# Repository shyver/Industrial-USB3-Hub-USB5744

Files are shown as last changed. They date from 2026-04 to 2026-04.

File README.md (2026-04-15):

# Industrial 4-Port USB 3.0 Hub (High-Speed Design)






## 📌 Project Overview
This repository contains the hardware design files for an industrial-grade, 4-port USB 3.0 (SuperSpeed 5Gbps) Hub. 

Designed around the **Microchip USB5744** hub controller, this project demonstrates advanced high-speed digital PCB design. It features a strict 4-layer stackup, precisely calculated 90Ω differential impedance routing, length-matching, robust ESD protection, and independent per-port power management. 

It is engineered to reliably convert a single USB-C upstream connection into four high-speed USB-A downstream ports in harsh or demanding environments.

*(Insert a screenshot of your routed PCB showing the differential pairs here later!)*

## ✨ Key Hardware Features
* **SuperSpeed Data (5 Gbps):** Full USB 3.1 Gen 1 compliance utilizing edge-coupled differential microstrip routing.
* **Impedance Control:** Mathematically calculated 90Ω differential impedance ($Z_{diff}$) tuned specifically for the JLC04161H-3313 manufacturing stackup.
* **Industrial Power Distribution:** Integrated power load switches providing dedicated, current-limited 5V power to each downstream port to prevent cascading short-circuit failures.
* **Heavy-Duty ESD Protection:** Ultra-low capacitance (< 0.5pF) TVS diode arrays on all SuperSpeed data lines to absorb transient voltage spikes without distorting multi-gigabit signal integrity.
* **Clean Clocking:** 25MHz external crystal oscillator with localized ground guarding to minimize EMI/Crosstalk.

## 📐 High-Speed PCB Specifications

To achieve reliable 5 Gbps data rates, standard 2-layer routing is insufficient. This board utilizes a custom 4-layer stackup to provide immediate, unbroken return paths for high-frequency signals.

* **Stackup Architecture:**
  * **Layer 1 (Top):** High-Speed Signals
  * **Layer 2 (In1):** Solid Ground Plane (Continuous Return Path)
  * **Layer 3 (In2):** Power Planes (5V, 3.3V, 1.2V)
  * **Layer 4 (Bottom):** Low-Speed Signals & Support Components
* **Impedance Math (USB 3.0 `SSTX`/`SSRX` & USB 2.0 `D+/D-`):**
  * Target Differential Impedance: **90 Ω ±10%**
  * Substrate Dielectric ($E_r$): **4.05**
  * Distance to Ground ($H$): **0.0964 mm**
  * Calculated Trace Width ($W$): **0.20 mm**
  * Calculated Trace Gap ($S$): **0.18 mm**

## 📂 Repository Structure
* `/Hardware` - KiCad 8.0 project files (`.kicad_sch`, `.kicad_pcb`).
* `/Docs` - Datasheets for the USB5744, Power Switches, and Ultra-low capacitance TVS diodes.
* `/Calculations` - Screenshots and data for the impedance and stackup calculations.
* `/Fabrication` - Gerber files, Drill files, BOM, and CPL files ready for PCBA.

## 🚀 Getting Started
1. Clone this repository: `git clone https://github.com/YourUsername/Industrial-USB3-Hub-USB5744.git`
2. Open the `.pro` or `.kicad_pro` file in **KiCad**.
3. *Note: Ensure your KiCad DRC rules are configured for the 4-layer constraints detailed above before modifying the layout.*

## 📝 License
This project is open-source and available under the [MIT License](LICENSE).

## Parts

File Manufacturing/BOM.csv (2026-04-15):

Reference | Qty | Value | DNP | Exclude from BOM | Exclude from Board | Footprint | Datasheet
C1,C2,C3,C4,C5,C6,C7,C8,C9,C10,C11,C12,C13,C14,C15,C16,C17,C18,C19,C22,C25,C26,C27,C28,C29,C30,C31,C33,C35 | 29 | 0.1µ |  |  |  | Capacitor_SMD:C_0201_0603Metric | ~
C20,C21,C32,C34,C36,C37 | 6 | 10µ |  |  |  | Capacitor_SMD:C_0201_0603Metric | ~
C23,C24 | 2 | 33p |  |  |  | Capacitor_SMD:C_0201_0603Metric | ~
C38,C42 | 2 | 22µ |  |  |  | Capacitor_SMD:C_0201_0603Metric | ~
C39,C43 | 2 | 6.8n |  |  |  | Capacitor_SMD:C_0201_0603Metric | ~
C40,C44 | 2 | 1µ |  |  |  | Capacitor_SMD:C_0201_0603Metric | ~
C41,C45 | 2 | 44µ |  |  |  | Capacitor_SMD:C_0201_0603Metric | ~
H1,H2 | 2 | MountingHole_Pad |  | Excluded from BOM |  | MountingHole:MountingHole_3.2mm_M3_Pad_Via | ~
J1,J3,J4,J6 | 4 | USB3_A |  |  |  | Connector_USB:USB3_A_Molex_48393-001 | ~
J2 | 1 | USB_C_Receptacle |  |  |  | personal_library:BELFUSE_SS-52400-003 | https://www.usb.org/sites/default/files/documents/usb_type-c.zip
L1,L2 | 2 | 1.5µ |  |  |  | Inductor_SMD:L_Taiyo-Yuden_NR-40xx | ~
R1,R5 | 2 | 887 |  |  |  | Resistor_SMD:R_0201_0603Metric | ~
R2,R7,R8,R9 | 4 | 5.6k |  |  |  | Resistor_SMD:R_0201_0603Metric | ~
R3 | 1 | 43k |  |  |  | Resistor_SMD:R_0201_0603Metric | ~
R4 | 1 | 49.9k |  |  |  | Resistor_SMD:R_0201_0603Metric | ~
R6 | 1 | 12k |  |  |  | Resistor_SMD:R_0201_0603Metric | ~
R10,R13,R14,R24 | 4 | 10k |  |  |  | Resistor_SMD:R_0201_0603Metric | ~
R11 | 1 | 10 |  |  |  | Resistor_SMD:R_0201_0603Metric | ~
R12 | 1 | 200k |  |  |  | Resistor_SMD:R_0201_0603Metric | ~
R15,R19 | 2 | 20 |  |  |  | Resistor_SMD:R_0201_0603Metric | ~
R16 | 1 | 30k |  |  |  | Resistor_SMD:R_0201_0603Metric | ~
R17,R21 | 2 | 40.2k |  |  |  | Resistor_SMD:R_0201_0603Metric | ~
R18 | 1 | 13k |  |  |  | Resistor_SMD:R_0201_0603Metric | ~
R20 | 1 | 75k |  |  |  | Resistor_SMD:R_0201_0603Metric | ~
R22 | 1 | 82k |  |  |  | Resistor_SMD:R_0201_0603Metric | ~
R23 | 1 | 100k |  |  |  | Resistor_SMD:R_0201_0603Metric | ~
TP1 | 1 | VBUS |  |  |  | TestPoint:TestPoint_Pad_1.0x1.0mm | ~
TP2 | 1 | 3V3 |  |  |  | TestPoint:TestPoint_Pad_1.0x1.0mm | ~
TP3,TP8 | 2 | 1V2 |  |  |  | TestPoint:TestPoint_Pad_1.0x1.0mm | ~
TP4 | 1 | GND |  |  |  | TestPoint:TestPoint_Pad_1.0x1.0mm | ~
TP5 | 1 | EN1 |  |  |  | TestPoint:TestPoint_Pad_1.0x1.0mm | ~
TP6 | 1 | EN2 |  |  |  | TestPoint:TestPoint_Pad_1.0x1.0mm | ~
TP7 | 1 | EN3 |  |  |  | TestPoint:TestPoint_Pad_1.0x1.0mm | ~
TP9 | 1 | RESET_N |  |  |  | TestPoint:TestPoint_Pad_1.0x1.0mm | ~
TP10 | 1 | DIR |  |  |  | TestPoint:TestPoint_Pad_1.0x1.0mm | ~
U1 | 1 | USB5744-I_2G |  |  |  | personal_library:USB5744-QFN40P700X700X100-57N
U2 | 1 | HD3SS3212IRKSR |  |  |  | personal_library:QFN50P450X250X100-21N
U3 | 1 | TUSB321 |  |  |  | Package_DFN_QFN:Texas_X2QFN-12_1.6x1.6mm_P0.4mm | http://www.ti.com/lit/ds/symlink/tusb321.pdf
U4,U5,U6,U7 | 4 | SY6280 |  |  |  | personal_library:SOT23-5
U8,U9 | 2 | MP2393GTL-P |  |  |  | MP2393GTL-P:SOT583_MP2393 | https://www.monolithicpower.com/en/documentview/productdocument/index/version/2/document_type/Datasheet/lang/en/sku/MP2393GTL-Z
Y1 | 1 | Crystal_GND24 |  |  |  | personal_library:403I35D25M00000 | ~

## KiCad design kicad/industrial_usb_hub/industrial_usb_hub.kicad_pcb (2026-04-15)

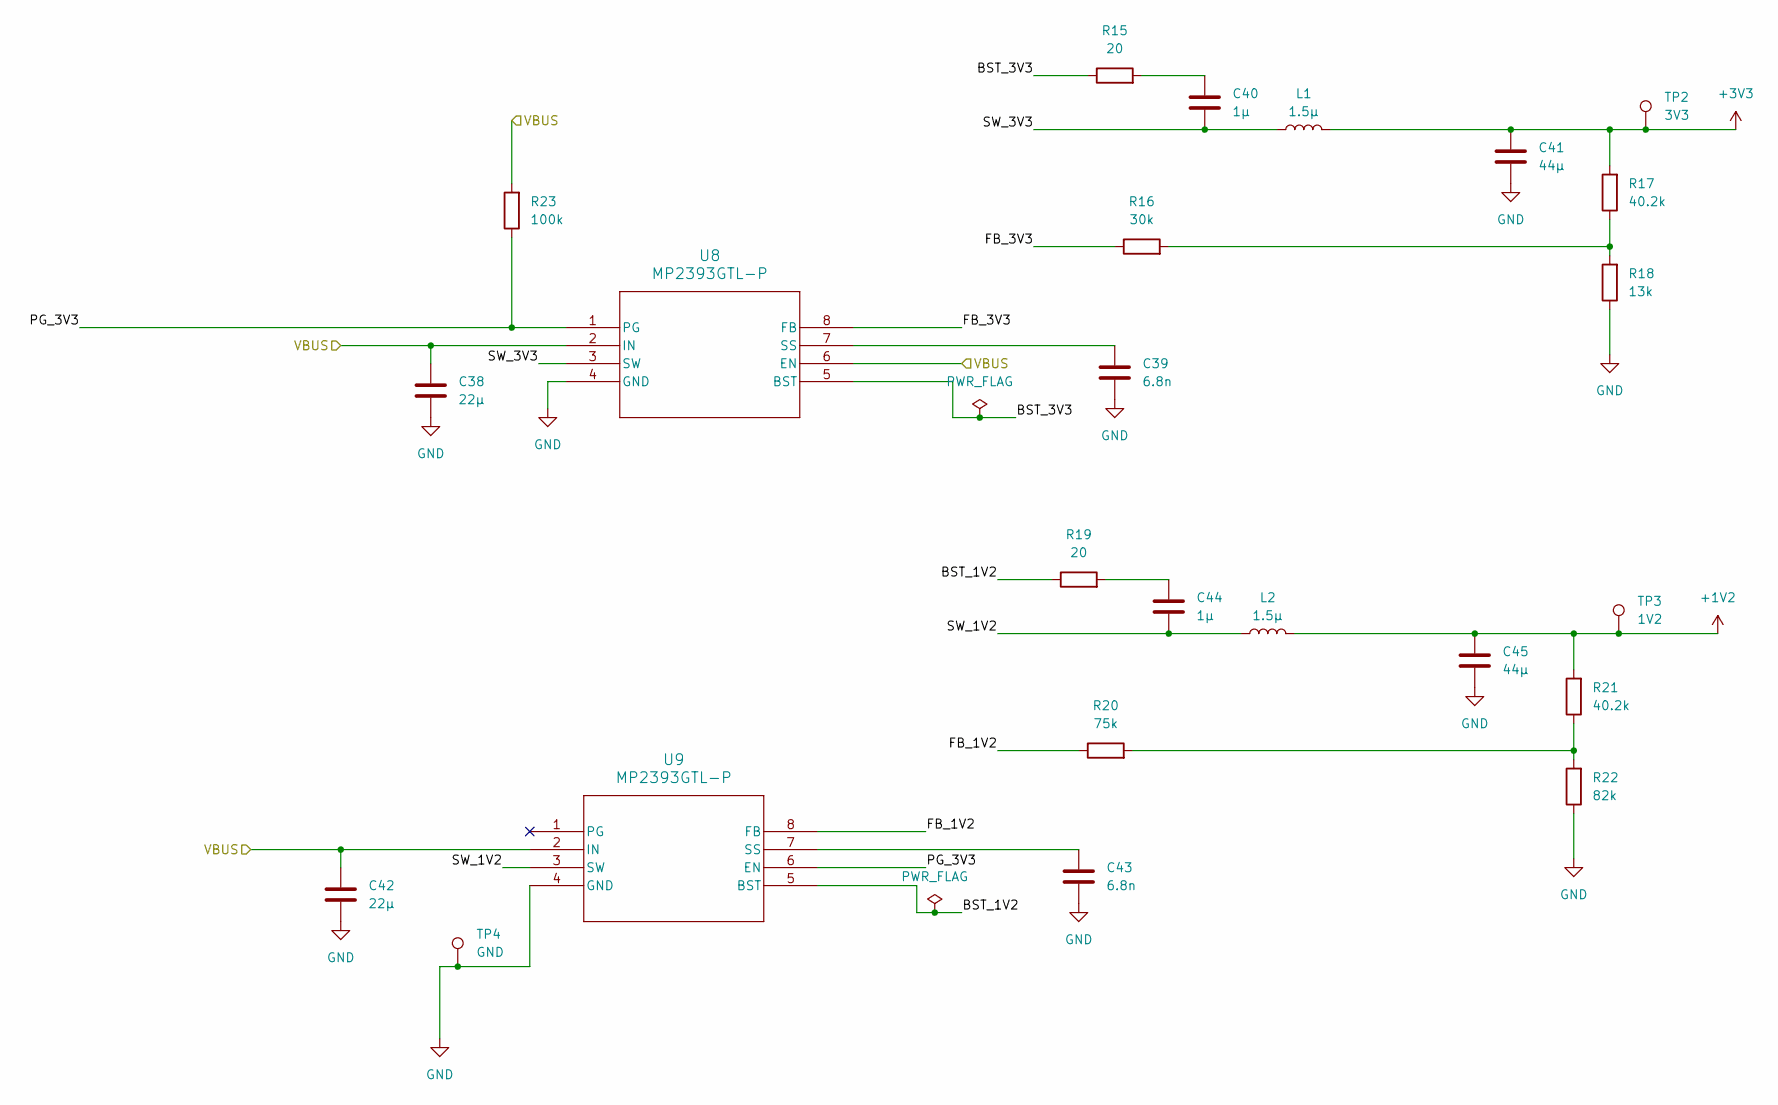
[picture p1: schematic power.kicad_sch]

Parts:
C38, C42: 22µ; C_0201_0603Metric
C39, C43: 6.8n; C_0201_0603Metric
C40, C44: 1µ; C_0201_0603Metric
C41, C45: 44µ; C_0201_0603Metric
L1, L2: 1.5µ; L_Taiyo-Yuden_NR-40xx
R15, R19: 20; R_0201_0603Metric
R16: 30k; R_0201_0603Metric
R17, R21: 40.2k; R_0201_0603Metric
R18: 13k; R_0201_0603Metric
R20: 75k; R_0201_0603Metric
R22: 82k; R_0201_0603Metric
R23: 100k; R_0201_0603Metric
TP2: 3V3; TestPoint_Pad_1.0x1.0mm
TP3: 1V2; TestPoint_Pad_1.0x1.0mm
TP4: GND; TestPoint_Pad_1.0x1.0mm
U8, U9: MP2393GTL-P; SOT583_MP2393

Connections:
+1V2: C45.1, L2.2, R21.2, TP3.1; also elsewhere on the board
+3V3: C41.1, L1.2, R17.2, TP2.1; also elsewhere on the board
/Downstream/VBUS: C38.1, C42.1, R23.2, U8.2 (IN), U8.6 (EN), U9.2 (IN); also elsewhere on the board
/Power/BST_1V2: R19.1, U9.5 (BST)
/Power/BST_3V3: R15.1, U8.5 (BST)
/Power/FB_1V2: R20.1, U9.8 (FB)
/Power/FB_3V3: R16.1, U8.8 (FB)
/Power/PG_3V3: R23.1, U8.1 (PG), U9.6 (EN)
/Power/SW_1V2: C44.2, L2.1, U9.3 (SW)
/Power/SW_3V3: C40.2, L1.1, U8.3 (SW)
GND: C38.2, C39.2, C41.2, C42.2, C43.2, C45.2, R18.1, R22.1, TP4.1, U8.4 (GND), U9.4 (GND); also elsewhere on the board
unnamed: C40.1, R15.2
unnamed: C44.1, R19.2
unnamed: R16.2, R17.1, R18.2
unnamed: R20.2, R21.1, R22.2
unnamed: C39.1, U8.7 (SS)
unnamed: C43.1, U9.7 (SS)

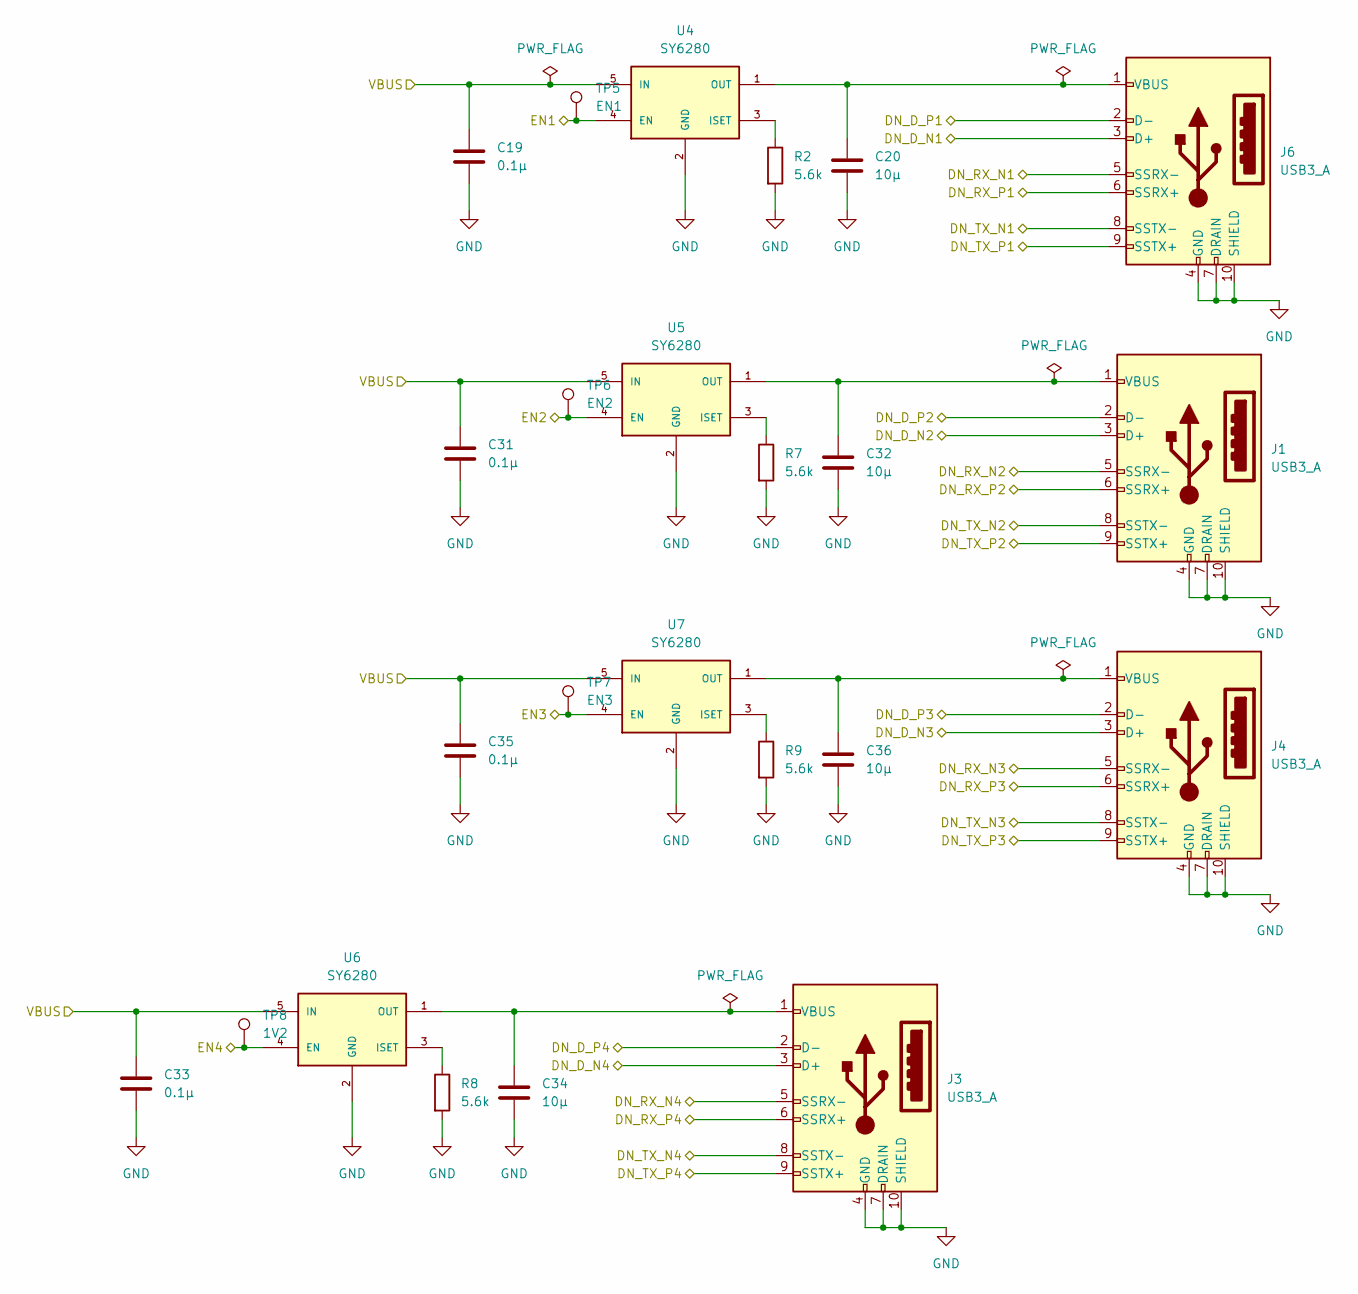
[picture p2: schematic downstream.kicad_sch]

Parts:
C19, C31, C33, C35: 0.1µ; C_0201_0603Metric
C20, C32, C34, C36: 10µ; C_0201_0603Metric
J1, J3, J4, J6: USB3_A; USB3_A_Molex_48393-001
R2, R7, R8, R9: 5.6k; R_0201_0603Metric
TP5: EN1; TestPoint_Pad_1.0x1.0mm
TP6: EN2; TestPoint_Pad_1.0x1.0mm
TP7: EN3; TestPoint_Pad_1.0x1.0mm
TP8: 1V2; TestPoint_Pad_1.0x1.0mm
U4, U5, U6, U7: SY6280; SOT23-5; PARTS SY6280

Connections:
/Downstream/DN_D_N1: J6.3 (D+); also elsewhere on the board
/Downstream/DN_D_N2: J1.3 (D+); also elsewhere on the board
/Downstream/DN_D_N3: J4.3 (D+); also elsewhere on the board
/Downstream/DN_D_N4: J3.3 (D+); also elsewhere on the board
/Downstream/DN_D_P1: J6.2 (D-); also elsewhere on the board
/Downstream/DN_D_P2: J1.2 (D-); also elsewhere on the board
/Downstream/DN_D_P3: J4.2 (D-); also elsewhere on the board
/Downstream/DN_D_P4: J3.2 (D-); also elsewhere on the board
/Downstream/DN_RX_N1: J6.5 (SSRX-); also elsewhere on the board
/Downstream/DN_RX_N2: J1.5 (SSRX-); also elsewhere on the board
/Downstream/DN_RX_N3: J4.5 (SSRX-); also elsewhere on the board
/Downstream/DN_RX_N4: J3.5 (SSRX-); also elsewhere on the board
/Downstream/DN_RX_P1: J6.6 (SSRX+); also elsewhere on the board
/Downstream/DN_RX_P2: J1.6 (SSRX+); also elsewhere on the board
/Downstream/DN_RX_P3: J4.6 (SSRX+); also elsewhere on the board
/Downstream/DN_RX_P4: J3.6 (SSRX+); also elsewhere on the board
/Downstream/DN_TX_N1: J6.8 (SSTX-); also elsewhere on the board
/Downstream/DN_TX_N2: J1.8 (SSTX-); also elsewhere on the board
/Downstream/DN_TX_N3: J4.8 (SSTX-); also elsewhere on the board
/Downstream/DN_TX_N4: J3.8 (SSTX-); also elsewhere on the board
/Downstream/DN_TX_P1: J6.9 (SSTX+); also elsewhere on the board
/Downstream/DN_TX_P2: J1.9 (SSTX+); also elsewhere on the board
/Downstream/DN_TX_P3: J4.9 (SSTX+); also elsewhere on the board
/Downstream/DN_TX_P4: J3.9 (SSTX+); also elsewhere on the board
/Downstream/EN1: TP5.1, U4.4 (EN); also elsewhere on the board
/Downstream/EN2: TP6.1, U5.4 (EN); also elsewhere on the board
/Downstream/EN3: TP7.1, U7.4 (EN); also elsewhere on the board
/Downstream/EN4: TP8.1, U6.4 (EN); also elsewhere on the board
/Downstream/VBUS: C19.2, C31.2, C33.2, C35.2, U4.5 (IN), U5.5 (IN), U6.5 (IN), U7.5 (IN); also elsewhere on the board
GND: C19.1, C20.1, C31.1, C32.1, C33.1, C34.1, C35.1, C36.1, J1.4 (GND), J1.7 (DRAIN), J1.10 (SHIELD), J3.4 (GND), J3.7 (DRAIN), J3.10 (SHIELD), J4.4 (GND), J4.7 (DRAIN), J4.10 (SHIELD), J6.4 (GND), J6.7 (DRAIN), J6.10 (SHIELD), R2.2, R7.2, R8.2, R9.2, U4.2 (GND), U5.2 (GND), U6.2 (GND), U7.2 (GND); also elsewhere on the board
unnamed: C32.2, J1.1 (VBUS), U5.1 (OUT)
unnamed: C34.2, J3.1 (VBUS), U6.1 (OUT)
unnamed: C36.2, J4.1 (VBUS), U7.1 (OUT)
unnamed: C20.2, J6.1 (VBUS), U4.1 (OUT)
unnamed: R2.1, U4.3 (ISET)
unnamed: R7.1, U5.3 (ISET)
unnamed: R8.1, U6.3 (ISET)
unnamed: R9.1, U7.3 (ISET)

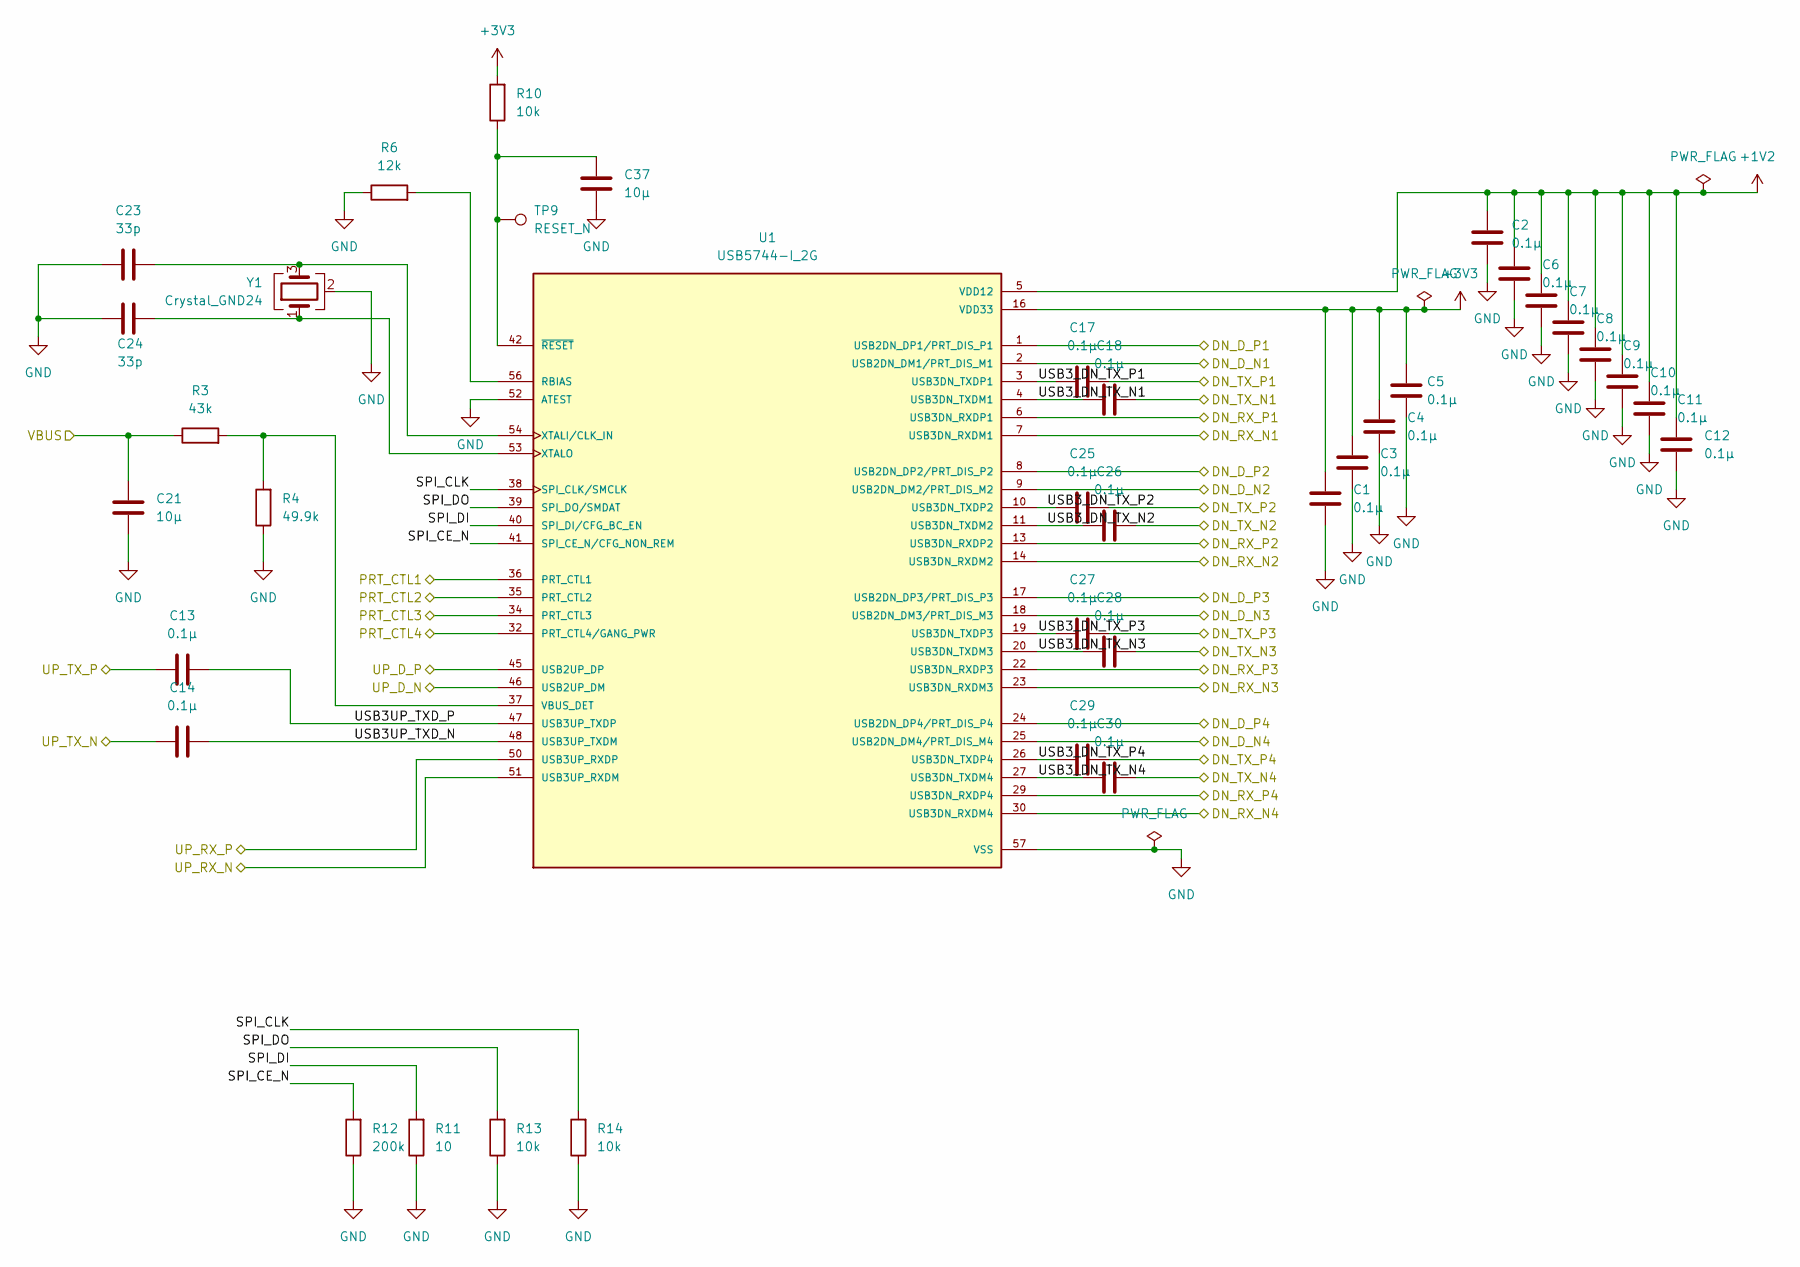
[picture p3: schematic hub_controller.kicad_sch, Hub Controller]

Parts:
C1, C2, C3, C4, C5, C6, C7, C8, C9, C10, C11, C12, C13, C14, C17, C18, C25, C26, C27, C28, C29, C30: 0.1µ; C_0201_0603Metric
C21, C37: 10µ; C_0201_0603Metric
C23, C24: 33p; C_0201_0603Metric
R3: 43k; R_0201_0603Metric
R4: 49.9k; R_0201_0603Metric
R6: 12k; R_0201_0603Metric
R10, R13, R14: 10k; R_0201_0603Metric
R11: 10; R_0201_0603Metric
R12: 200k; R_0201_0603Metric
TP9: RESET_N; TestPoint_Pad_1.0x1.0mm
U1: USB5744-I_2G; USB5744-QFN40P700X700X100-57N; PARTREV DS00001855J
Y1: Crystal_GND24; 403I35D25M00000

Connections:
+1V2: C2.1, C6.1, C7.1, C8.1, C9.1, C10.1, C11.1, C12.1, U1.5 (VDD12), U1.12 (VDD12), U1.15 (VDD12), U1.21 (VDD12), U1.28 (VDD12), U1.33 (VDD12), U1.43 (VDD12), U1.49 (VDD12); also elsewhere on the board
+3V3: C1.1, C3.1, C4.1, C5.1, R10.2, U1.16 (VDD33), U1.31 (VDD33), U1.44 (VDD33), U1.55 (VDD33); also elsewhere on the board
/Downstream/DN_D_N1: U1.2 (USB2DN_DM1/PRT_DIS_M1); also elsewhere on the board
/Downstream/DN_D_N2: U1.9 (USB2DN_DM2/PRT_DIS_M2); also elsewhere on the board
/Downstream/DN_D_N3: U1.18 (USB2DN_DM3/PRT_DIS_M3); also elsewhere on the board
/Downstream/DN_D_N4: U1.25 (USB2DN_DM4/PRT_DIS_M4); also elsewhere on the board
/Downstream/DN_D_P1: U1.1 (USB2DN_DP1/PRT_DIS_P1); also elsewhere on the board
/Downstream/DN_D_P2: U1.8 (USB2DN_DP2/PRT_DIS_P2); also elsewhere on the board
/Downstream/DN_D_P3: U1.17 (USB2DN_DP3/PRT_DIS_P3); also elsewhere on the board
/Downstream/DN_D_P4: U1.24 (USB2DN_DP4/PRT_DIS_P4); also elsewhere on the board
/Downstream/DN_RX_N1: U1.7 (USB3DN_RXDM1); also elsewhere on the board
/Downstream/DN_RX_N2: U1.14 (USB3DN_RXDM2); also elsewhere on the board
/Downstream/DN_RX_N3: U1.23 (USB3DN_RXDM3); also elsewhere on the board
/Downstream/DN_RX_N4: U1.30 (USB3DN_RXDM4); also elsewhere on the board
/Downstream/DN_RX_P1: U1.6 (USB3DN_RXDP1); also elsewhere on the board
/Downstream/DN_RX_P2: U1.13 (USB3DN_RXDP2); also elsewhere on the board
/Downstream/DN_RX_P3: U1.22 (USB3DN_RXDP3); also elsewhere on the board
/Downstream/DN_RX_P4: U1.29 (USB3DN_RXDP4); also elsewhere on the board
/Downstream/DN_TX_N1: C18.2; also elsewhere on the board
/Downstream/DN_TX_N2: C26.2; also elsewhere on the board
/Downstream/DN_TX_N3: C28.2; also elsewhere on the board
/Downstream/DN_TX_N4: C30.2; also elsewhere on the board
/Downstream/DN_TX_P1: C17.2; also elsewhere on the board
/Downstream/DN_TX_P2: C25.2; also elsewhere on the board
/Downstream/DN_TX_P3: C27.2; also elsewhere on the board
/Downstream/DN_TX_P4: C29.2; also elsewhere on the board
/Downstream/EN1: U1.36 (PRT_CTL1); also elsewhere on the board
/Downstream/EN2: U1.35 (PRT_CTL2); also elsewhere on the board
/Downstream/EN3: U1.34 (PRT_CTL3); also elsewhere on the board
/Downstream/EN4: U1.32 (PRT_CTL4/GANG_PWR); also elsewhere on the board
/Downstream/VBUS: C21.2, R3.1; also elsewhere on the board
/Hub Controller/SPI_CE_N: R12.2, U1.41 (SPI_CE_N/CFG_NON_REM)
/Hub Controller/SPI_CLK: R14.2, U1.38 (SPI_CLK/SMCLK)
/Hub Controller/SPI_DI: R11.2, U1.40 (SPI_DI/CFG_BC_EN)
/Hub Controller/SPI_DO: R13.2, U1.39 (SPI_DO/SMDAT)
/Hub Controller/UP_D_N: U1.46 (USB2UP_DM); also elsewhere on the board
/Hub Controller/UP_D_P: U1.45 (USB2UP_DP); also elsewhere on the board
/Hub Controller/UP_RX_N: U1.51 (USB3UP_RXDM); also elsewhere on the board
/Hub Controller/UP_RX_P: U1.50 (USB3UP_RXDP); also elsewhere on the board
/Hub Controller/UP_TX_N: C14.1; also elsewhere on the board
/Hub Controller/UP_TX_P: C13.1; also elsewhere on the board
/Hub Controller/USB3UP_TXD_N: C14.2, U1.48 (USB3UP_TXDM)
/Hub Controller/USB3UP_TXD_P: C13.2, U1.47 (USB3UP_TXDP)
/Hub Controller/USB3_DN_TX_N1: C18.1, U1.4 (USB3DN_TXDM1)
/Hub Controller/USB3_DN_TX_N2: C26.1, U1.11 (USB3DN_TXDM2)
/Hub Controller/USB3_DN_TX_N3: C28.1, U1.20 (USB3DN_TXDM3)
/Hub Controller/USB3_DN_TX_N4: C30.1, U1.27 (USB3DN_TXDM4)
/Hub Controller/USB3_DN_TX_P1: C17.1, U1.3 (USB3DN_TXDP1)
/Hub Controller/USB3_DN_TX_P2: C25.1, U1.10 (USB3DN_TXDP2)
/Hub Controller/USB3_DN_TX_P3: C27.1, U1.19 (USB3DN_TXDP3)
/Hub Controller/USB3_DN_TX_P4: C29.1, U1.26 (USB3DN_TXDP4)
GND: C1.2, C2.2, C3.2, C4.2, C5.2, C6.2, C7.2, C8.2, C9.2, C10.2, C11.2, C12.2, C21.1, C23.2, C24.2, C37.1, R4.1, R6.1, R11.1, R12.1, R13.1, R14.1, U1.52 (ATEST), U1.57 (VSS), Y1.2 (G), Y1.4 (G); also elsewhere on the board
unnamed: R6.2, U1.56 (RBIAS)
unnamed: R3.2, R4.2, U1.37 (VBUS_DET)
unnamed: C23.1, U1.54 (XTALI/CLK_IN), Y1.3
unnamed: C24.1, U1.53 (XTALO), Y1.1
unnamed: C37.2, R10.1, TP9.1, U1.42 (~RESET)

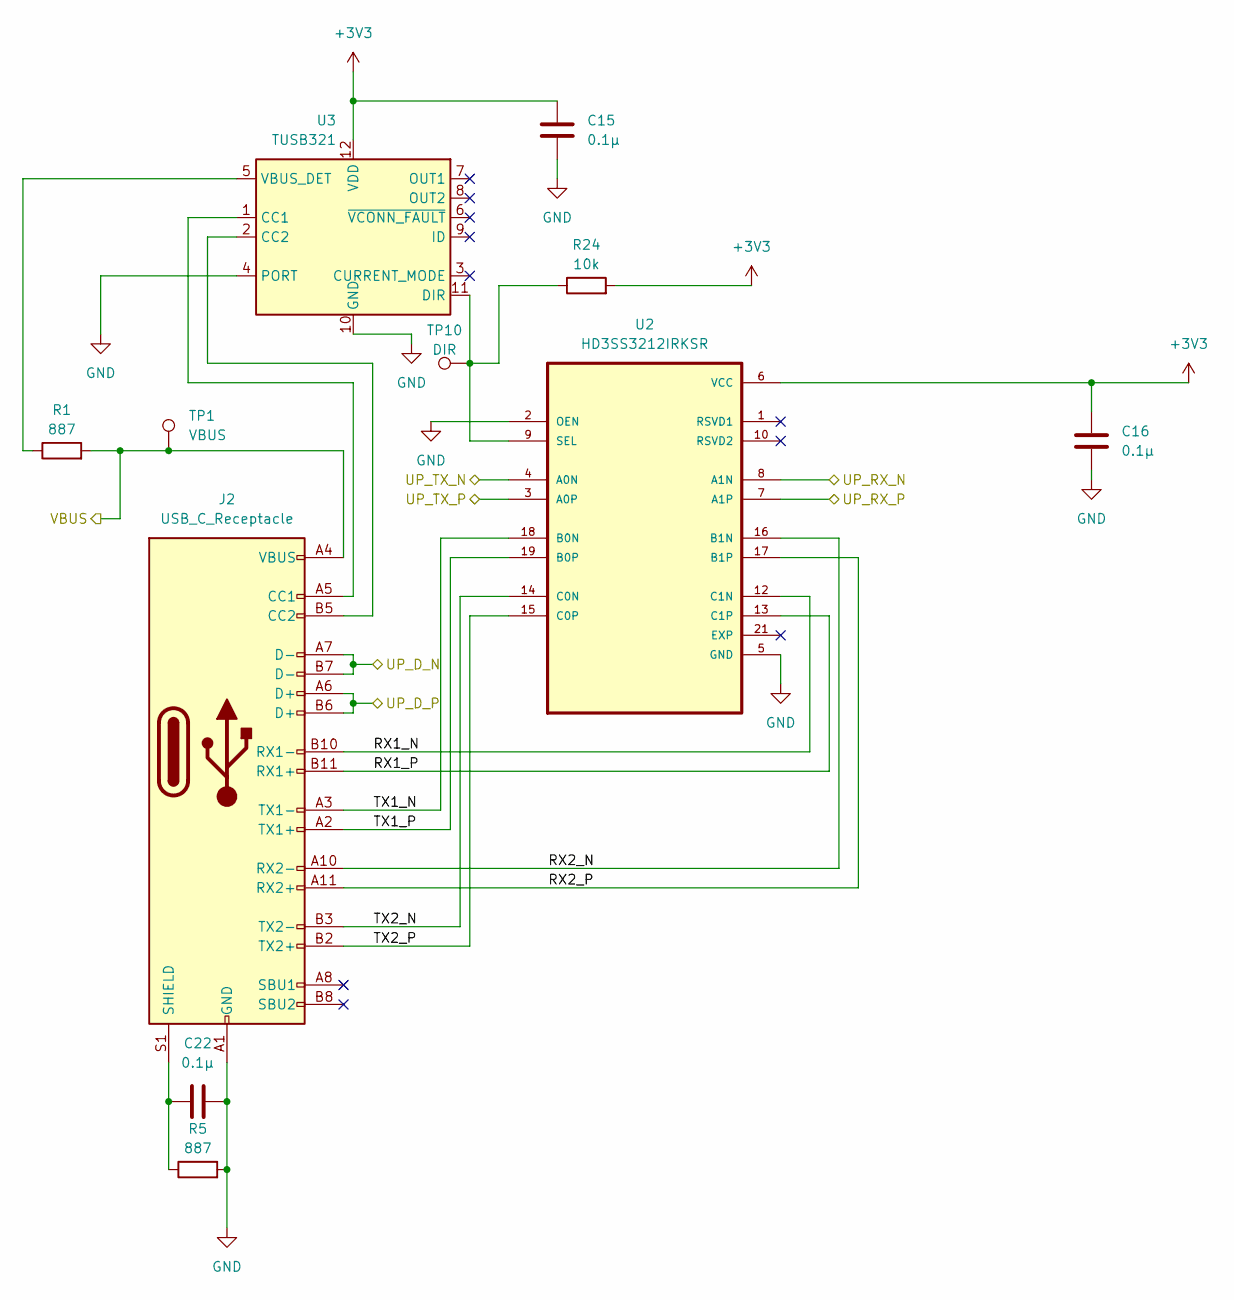
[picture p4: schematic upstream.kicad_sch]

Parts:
C15, C16, C22: 0.1µ; C_0201_0603Metric
J2: USB_C_Receptacle; BELFUSE_SS-52400-003
R1, R5: 887; R_0201_0603Metric
R24: 10k; R_0201_0603Metric
TP1: VBUS; TestPoint_Pad_1.0x1.0mm
TP10: DIR; TestPoint_Pad_1.0x1.0mm
U2: HD3SS3212IRKSR; QFN50P450X250X100-21N
U3: TUSB321; Texas_X2QFN-12_1.6x1.6mm_P0.4mm

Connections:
+3V3: C15.1, C16.1, R24.2, U2.6 (VCC), U3.12 (VDD); also elsewhere on the board
/Downstream/VBUS: J2.A4 (VBUS), J2.A9 (VBUS), J2.B4 (VBUS), J2.B9 (VBUS), R1.2, TP1.1; also elsewhere on the board
/Hub Controller/UP_D_N: J2.A7 (D-), J2.B7 (D-); also elsewhere on the board
/Hub Controller/UP_D_P: J2.A6 (D+), J2.B6 (D+); also elsewhere on the board
/Hub Controller/UP_RX_N: U2.8 (A1N); also elsewhere on the board
/Hub Controller/UP_RX_P: U2.7 (A1P); also elsewhere on the board
/Hub Controller/UP_TX_N: U2.4 (A0N); also elsewhere on the board
/Hub Controller/UP_TX_P: U2.3 (A0P); also elsewhere on the board
/Upstream/RX1_N: J2.B10 (RX1-), U2.12 (C1N)
/Upstream/RX1_P: J2.B11 (RX1+), U2.13 (C1P)
/Upstream/RX2_N: J2.A10 (RX2-), U2.16 (B1N)
/Upstream/RX2_P: J2.A11 (RX2+), U2.17 (B1P)
/Upstream/TX1_N: J2.A3 (TX1-), U2.18 (B0N)
/Upstream/TX1_P: J2.A2 (TX1+), U2.19 (B0P)
/Upstream/TX2_N: J2.B3 (TX2-), U2.14 (C0N)
/Upstream/TX2_P: J2.B2 (TX2+), U2.15 (C0P)
EXP: U2.21 (EXP)
GND: C15.2, C16.2, C22.2, J2.A1 (GND), J2.A12 (GND), J2.B1 (GND), J2.B12 (GND), R5.2, U2.2 (OEN), U2.5 (GND), U2.11 (GND), U2.20 (GND), U3.4 (PORT), U3.10 (GND); also elsewhere on the board
unnamed: J2.A5 (CC1), U3.1 (CC1)
unnamed: J2.B5 (CC2), U3.2 (CC2)
unnamed: C22.1, J2.S1 (SHIELD), R5.1
unnamed: R24.1, TP10.1, U2.9 (SEL), U3.11 (DIR)
unnamed: R1.1, U3.5 (VBUS_DET)

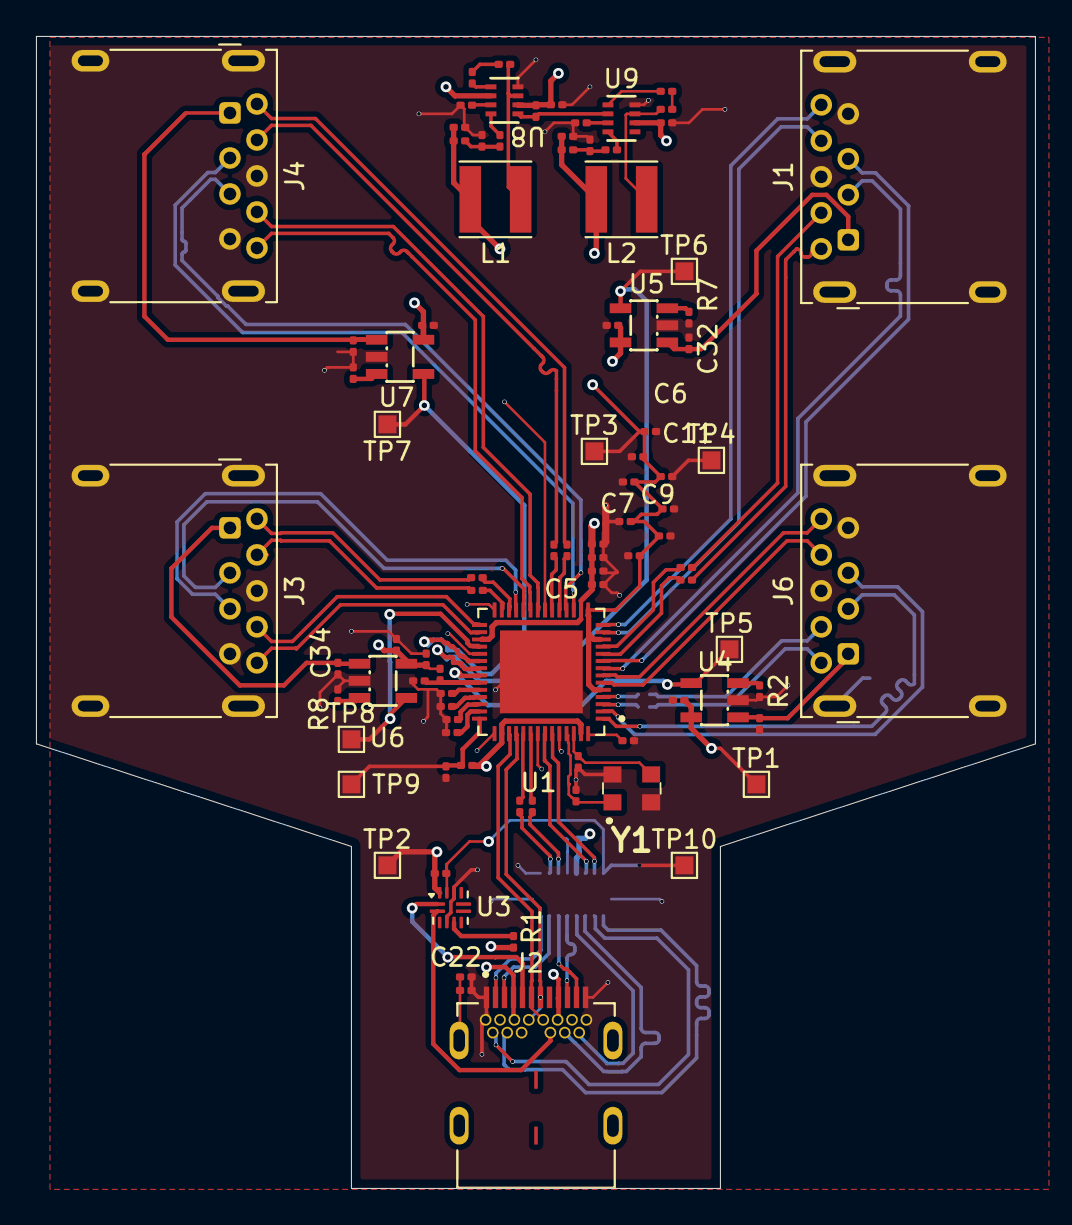
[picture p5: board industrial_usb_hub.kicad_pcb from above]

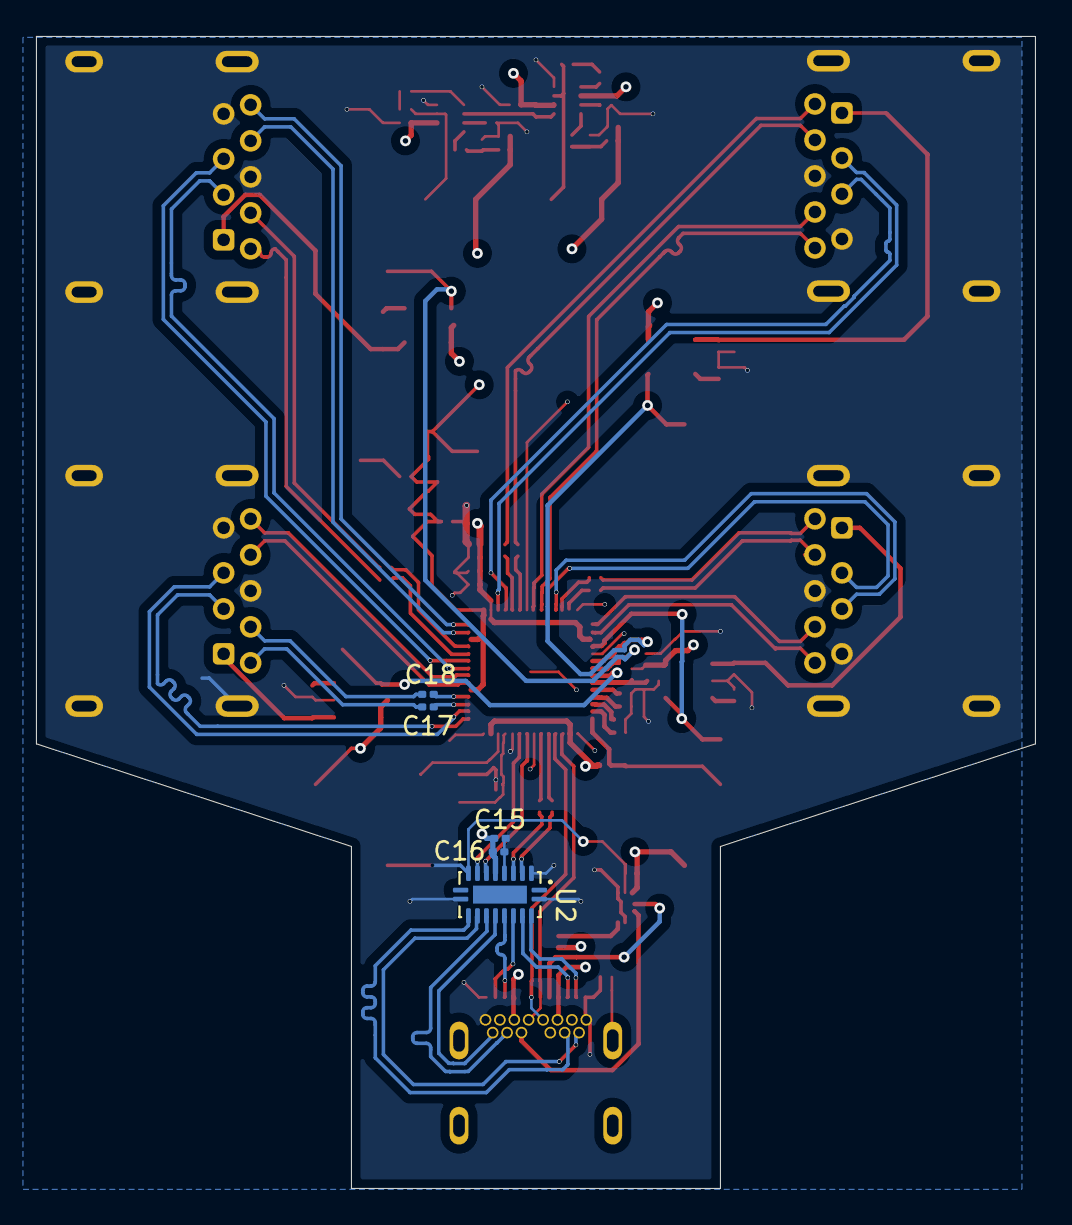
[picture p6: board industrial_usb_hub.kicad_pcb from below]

Board: 4 copper layers, 55.5 x 64.0 mm, 96 parts (5 on the bottom side), 91 nets.

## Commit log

2026-04-01 initiated project, configured board, created some sheets in the schematic
    [downstream.kicad_sch, hub_controller.kicad_sch, industrial_usb_hub.kicad_pcb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]
2026-04-10 completed upstream circuit, moving on to power and downstream
    [hub_controller.kicad_sch, industrial_usb_hub.kicad_sch, power.kicad_sch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]
2026-04-11 completed schematic
    [downstream.kicad_sch, hub_controller.kicad_sch, industrial_usb_hub.kicad_sch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]
2026-04-11 assigned footprints
    [downstream.kicad_sch, hub_controller.kicad_sch, power.kicad_sch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]
2026-04-12 moved on to pcb editor, chose component placements, groups, now needs routing, and bro routing superspeed just sucks
    [downstream.kicad_sch, industrial_usb_hub.kicad_pcb, upstream.kicad_sch]
2026-04-14 routed the USB C cables, fuck that was annoying, but at some point it just, got easier randomly? at an instant, didn't even notice it
    [industrial_usb_hub.kicad_pcb]
2026-04-14 okay okay it seems easier to do differential routing, feels menacing tho
    [hub_controller.kicad_sch, industrial_usb_hub.kicad_pcb]
2026-04-15 done routing, now fixing DRC errors (it's hatin)
    [hub_controller.kicad_sch, industrial_usb_hub.kicad_pcb]
2026-04-15 finalized routing, fixed DRC issues, imported the 3D models, all good
    [industrial_usb_hub.kicad_pcb]
2026-04-15 added testpoints
    [downstream.kicad_sch, hub_controller.kicad_sch, industrial_usb_hub.kicad_pcb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]
